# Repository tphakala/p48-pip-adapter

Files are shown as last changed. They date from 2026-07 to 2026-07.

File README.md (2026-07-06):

# P48 → 8 V PIP adapter (fits inside an XLR connector)

An ultra-compact **phantom-power (24-48 V) to 8 V plug-in-power (PIP)** adapter
board for high-sensitivity electret condenser capsules such as the PUI Audio
**AOM-5024**. The whole circuit lives on a **11.1 × 35.3 × 0.8 mm** four-layer
PCB thin enough to slip *between* the pins of a Neutrik **NC3MXX** male XLR and
solder to them directly, so a two-wire electret becomes a self-contained,
buffered, impedance-balanced phantom mic with nothing hanging off the back. It
runs on standard phantom power from any mixer, audio interface (such as a
Focusrite Scarlett), or field recorder.

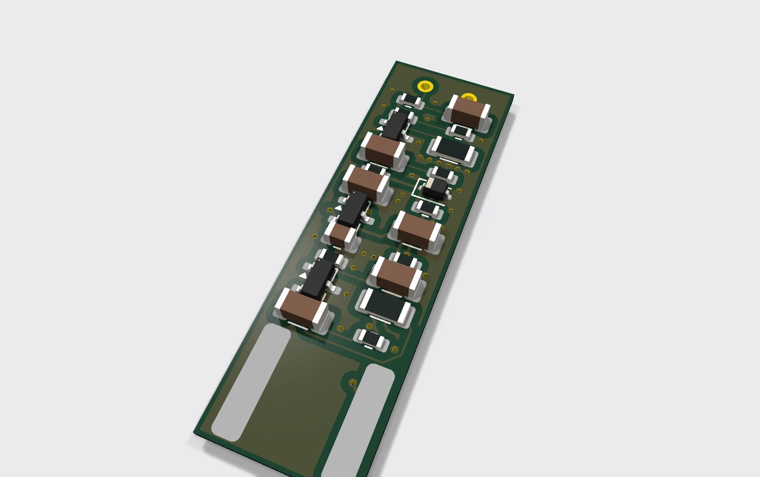
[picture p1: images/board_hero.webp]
Populated adapter board


This is the active-electronics counterpart to the 3D-printed
[`aom5024-xlr`](https://github.com/tphakala/aom5024-xlr) pencil-mic housing.
That project runs the capsule on a bare resistor + capacitor (fine for short
cable runs); this board is the buffered, impedance-balanced front end it points
to for long cables and true common-mode rejection, squeezed onto a board that
still fits inside the connector.

> **Order the bare board as 0.8 mm thick.** The thin edge has to fit into the
> gap between the three Neutrik pins; a standard 1.6 mm board is far too thick.
> This is a deliberate, load-bearing spec, not a default you can ignore.

## How it works

The circuit is three parts, one per section below: a capacitance-multiplier
supply that cleans up the phantom rail, a matched pair of Class-A buffers that
drive the cable, and a current split that keeps the DC draw equal on both
phantom pins.

### 1. Power supply: capacitance multiplier

Rather than running the capsule off a noisy Zener directly, the supply is a
**capacitance multiplier**:

- Phantom power is tapped equally from XLR pins 2 and 3.
- An 8.2 V Zener (D1) sets a raw voltage reference.
- A large RC low-pass (100 kΩ + 22 µF) puts the corner well below 1 Hz,
  scrubbing the Zener's avalanche noise off the reference.
- An NPN emitter follower (Q1) buffers that silent reference to the ~7.5 V
  PIP rail that biases the capsule.

### 2. Audio stage: impedance-balanced Class-A buffer

A two-wire electret can't produce a true differential signal on its own, so the
board fakes a balanced line the preamp can't tell from the real thing:

- **Pin 2 (hot)** is driven by a PNP emitter follower (Q2), a Class-A buffer
  that converts the capsule's high output impedance to a low ~78 Ω that
  drives long cable without treble roll-off.
- **Pin 3 (cold)** uses an identical PNP (Q3) with its base AC-grounded: no
  audio, but it matches Q2's ~78 Ω output impedance exactly.
- To the preamp this looks like a balanced source, so common-mode hum and RF
  cancel.

### 3. DC current balancing

The circuit pulls roughly **3 mA per pin**, a balanced DC draw that suits any
balanced input, whether electronically balanced (most audio interfaces and
modern preamps) or transformer-coupled: pin 2 feeds the hot buffer (Q2); pin 3
feeds the cold buffer (Q3) plus the regulator.

## Simulated performance

The circuit is verified headlessly in **ngspice**. The deck is generated from
[`netlist.py`](netlist.py), the same single source of truth as the board and
schematic, so the simulation can't drift from the hardware. `sim/run.ps1`
range-checks 17 design assertions; `sim/plot_response.py` sweeps the wide-band
response below (10 Hz – 384 kHz).

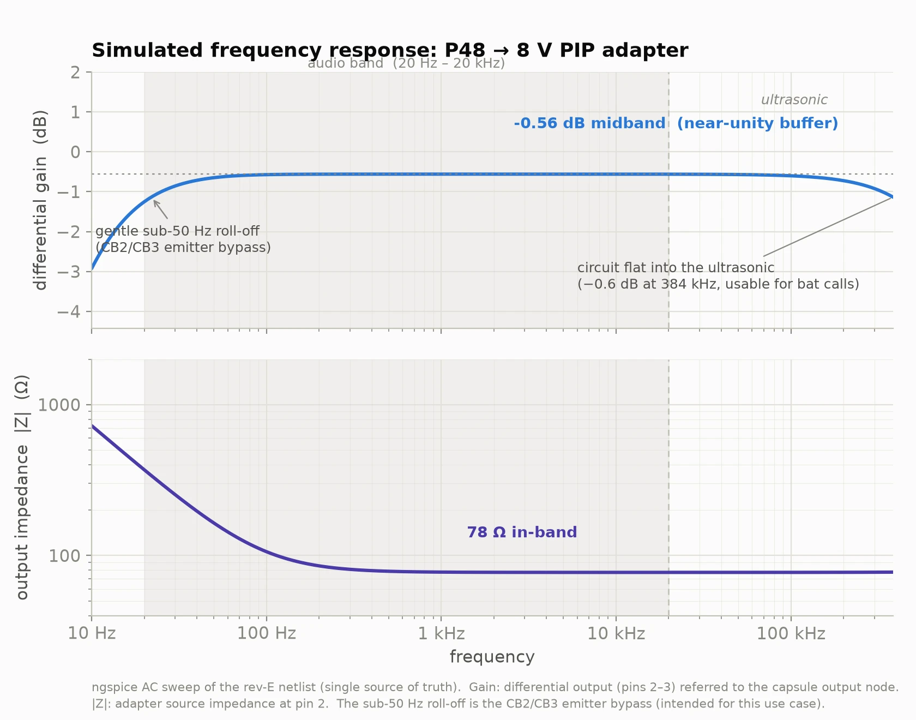
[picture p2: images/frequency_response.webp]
Simulated frequency response


- **Flat through the audio band** at −0.56 dB (a near-unity buffer), driving a
  modelled ~30 m cable into a 2 kΩ preamp.
- **Flat well into the ultrasonic**: only ~0.6 dB down at **384 kHz** (the
  192 kHz Nyquist of a 384 kHz sample rate). The trace is referred to the
  capsule output node, so it shows the *adapter electronics in isolation*: with
  a wide-band capsule the circuit is not the bottleneck for ultrasonic work such
  as **bat-call recording**. (The stock AOM-5024 electret rolls off far earlier;
  swap it for an ultrasonic-capable capsule for that use.)
- **~78 Ω source impedance**, flat from the audio band into the ultrasonic, low
  enough to drive long cable without HF loss and to look benign to any balanced
  input.
- The **gentle sub-50 Hz roll-off** is the CB2/CB3 emitter bypass, and it is
  deliberate: some LF attenuation is desirable here and it keeps those bypass
  caps small.

See [`sim/README.md`](sim/README.md) for the harness and the full assertion list.

## The board

Four copper layers, everything on the **top** side for single-sided assembly.
The two inner layers are **solid ground planes**, a real on-board Faraday cage
for the µV front end, via-stitched to the outer ground pours and to the XLR
pin-1 ground, backing up the grounded zinc shell:

| Layer | Net / role |
| :-- | :-- |
| **F.Cu** | signal routing + all component placement, GND flood-fill |
| **In1.Cu** | solid ground plane (shield / image plane under the signal) |
| **In2.Cu** | solid ground plane (second reference for the back-side routing) |
| **B.Cu** | GND pour + the few signal escapes + the XLR pin-3 pad |

Signal routing is confined to the outer layers so the inner planes stay
unbroken; the supply nets (P2/P3/VPIP/VREF) use a wider 0.25 mm **Power**
netclass, while GND is distributed by the planes rather than as tracks.

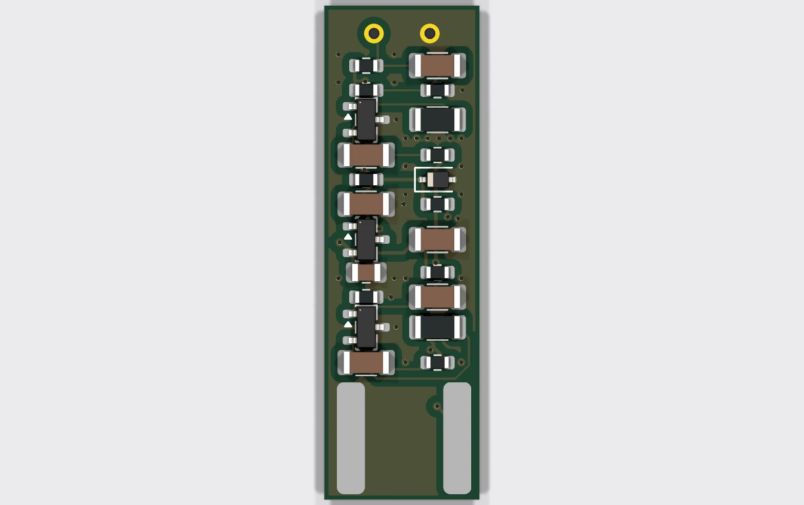
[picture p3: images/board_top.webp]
Top side, the two-column component layout


### XLR sandwich mount

The thin board edge slides **between** the three NC3MXX pins (7.62 mm cup
spacing) and the pins solder to the board faces, pins 1 and 2 on the front and
pin 3 on the back:

| Pin | Net | Face | x (mm) |
| :-- | :-- | :-- | :-- |
| 1 | GND | front | 1.90 |
| 2 | hot | front | 9.52 |
| 3 | cold | back | 5.71 |

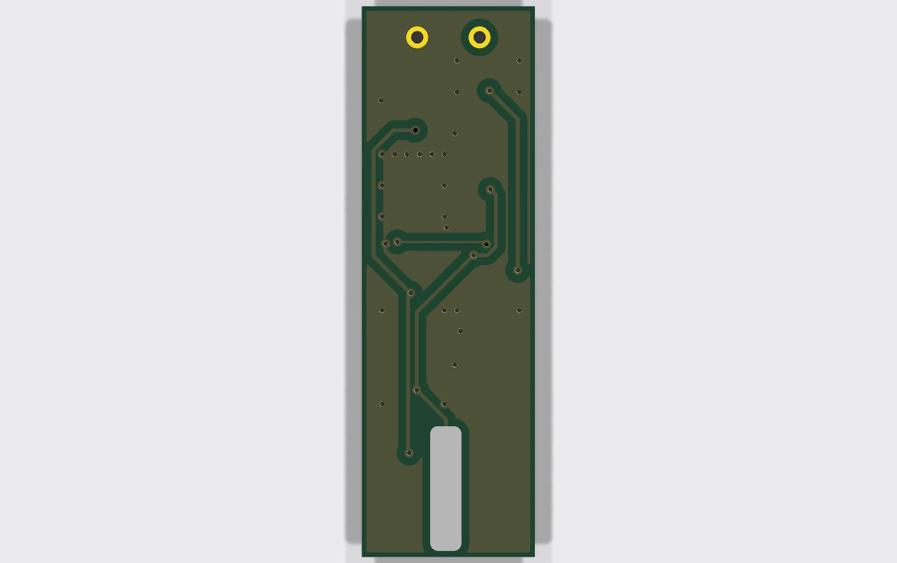
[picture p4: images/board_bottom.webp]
Reverse side: the centred pin-3 pad


The three XLR pads are **8 mm long**: the internal Neutrik pin runs ~5 mm along
the board and the pad extends 3 mm past the pin tip so there's copper to hand-
solder to. The pin tip keeps ≥ 5 mm clearance to the nearest component; the
35.3 mm board length is *derived* from that constraint in `netlist.py`.

The board's thin edge slots straight **between** the three XLR pins (pins 1 & 2
against the front component face, pin 3 against the back), with the pad end
seated against the connector body and the mating pins left free for the preamp.

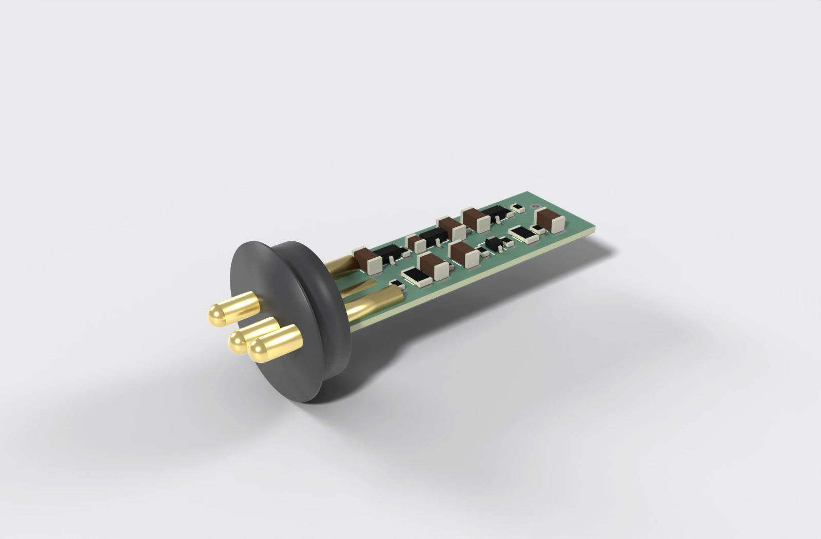
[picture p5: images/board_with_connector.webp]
The board slotted between the three pins of an XLR connector


<sub>The bare pin insert is modelled at this board's actual XLR-pad positions
(from `netlist.py`) to show the sandwich mount; the Neutrik NC3MXX STEP is one
fused solid whose pins can't be isolated, so the pins are drawn to match.</sub>

## Schematic

The full circuit, drawn from [`netlist.py`](netlist.py), the single source of
truth. On the left, the capacitance-multiplier reference/regulator (D1 zener,
R9/C4 sub-1 Hz filter, Q1 emitter follower) produces the clean **VPIP** rail; R10
biases the capsule; and the two impedance-matched PNP emitter followers (Q2 hot,
Q3 cold) draw the balanced ~3 mA per phantom pin, each with its CBx/RBx emitter-
bypass network for the low-Z output. This figure is drawn directly from the same
netlist that synthesizes the board, so the two cannot disagree.

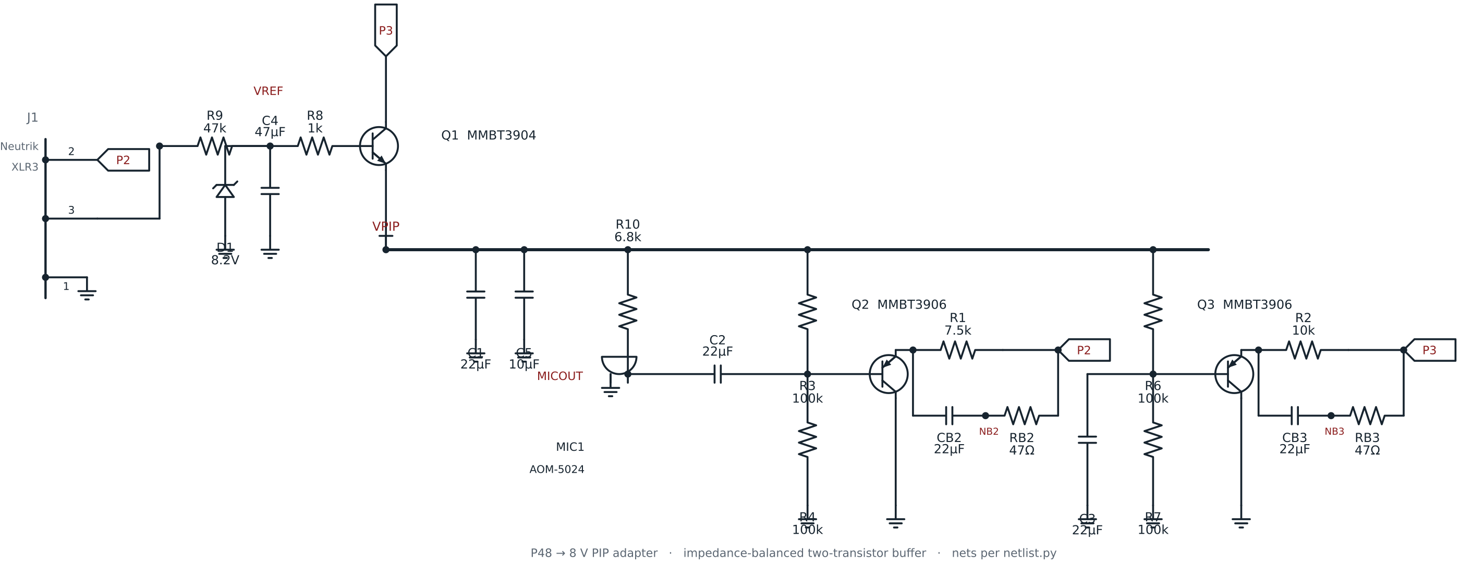
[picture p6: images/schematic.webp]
Schematic


## Bill of materials

All parts are SMD to fit the 11.1 mm width. Component values are nominal
(derived from the architecture and standard P48→PIP practice) and may benefit
from bench tuning before a production run.

| Ref | Value | Package | Function |
| :-- | :-- | :-- | :-- |
| Q1 | MMBT3904 | SOT-23 | NPN, regulator emitter follower |
| Q2, Q3 | MMBT3906 | SOT-23 | PNP, hot / cold audio buffers |
| D1 | 8.2 V Zener | SOD-323 | voltage reference |
| C1, C2, C3 | 22 µF 50 V | 1206 | filtering / DC blocking |
| C4 | 47 µF 50 V | 1206 | VREF filter (sub-1 Hz corner) |
| C5 | 10 µF 16 V | 0805 | PIP rail bypass |
| CB2, CB3 | 22 µF 50 V X7R | 1206 | emitter bypass → low-Z output |
| R1 | 7.5 kΩ | 1206 | hot buffer emitter feed (thermal, 1206) |
| R2 | 10 kΩ | 1206 | cold buffer emitter feed (thermal, 1206) |
| R3, R4, R6, R7 | 100 kΩ | 0603 | bias dividers |
| R8 | 1 kΩ | 0603 | regulator base stopper |
| R9 | 47 kΩ | 0603 | VREF feed |
| R10 | 6.8 kΩ | 0603 | mic bias |
| RB2, RB3 | 47 Ω | 0603 | emitter-bypass series stopper (cable stability) |

R1/R2 are **1206** (not 0603): each dissipates continuously inside the sealed
XLR shell, and 1206's 250 mW rating keeps a comfortable margin at 80 °C ambient.
CB2/CB3 sit across ~23 V DC, so they **must be 50 V rated** (X7R). There is
intentionally **no R5**. The full derived netlist (the single source of truth)
lives in [`netlist.py`](netlist.py) and is documented in [SPEC.md](SPEC.md); the
board is synthesized from it (schematic-free) and the schematic figure above is
drawn from the same netlist, so they cannot disagree.

## Manufacturing status

- **4-layer, 11.1 × 35.3 × 0.8 mm**, all parts top-side (single-sided assembly).
- **DRC: 0 errors, 0 unconnected pads, 0 footprint errors** (`kicad-cli pcb drc`).
- Track 0.15 mm (0.25 mm on the Power netclass), clearance 0.125 mm, vias
  0.6 / 0.3 mm, copper-to-edge ≥ 0.25 mm, solid In1/In2 ground planes with GND
  via stitching, all within JLCPCB / PCBWay standard 4-layer capability.
- Fab package: Gerber X2 + Excellon drill (PTH/NPTH separated) in
  [`Gerbers_PCBWay/`](Gerbers_PCBWay), zipped as `P48_Adapter_PCBWay.zip`.

**Known trade-off.** At 11.1 mm wide with six 1206 caps and two 1206 resistors,
the KiCad *courtyards* (assembly keep-out margins, ~4.7 mm for a 1206) unavoidably
overlap. There are no copper shorts (pad-to-pad clearance is fully enforced), so
the `courtyards_overlap` rule is downgraded to a warning. To remove it entirely,
move the 1206 parts to smaller packages or widen the board. Silkscreen reference
designators are hidden (illegible at this density); use the BOM and placement
data for assembly.

## Mechanical fit test

Before committing to a fab run, print `fit_test/p48_fittest.stl` and check the
board actually fits inside your connector. It's a single manifold solid: the
exact 0.8 mm outline, capsule through-holes, every component embossed at true
body size and height, raised solder pads, and the three long flat XLR solder
pads running along the board from the connector edge. Print flat, components up.

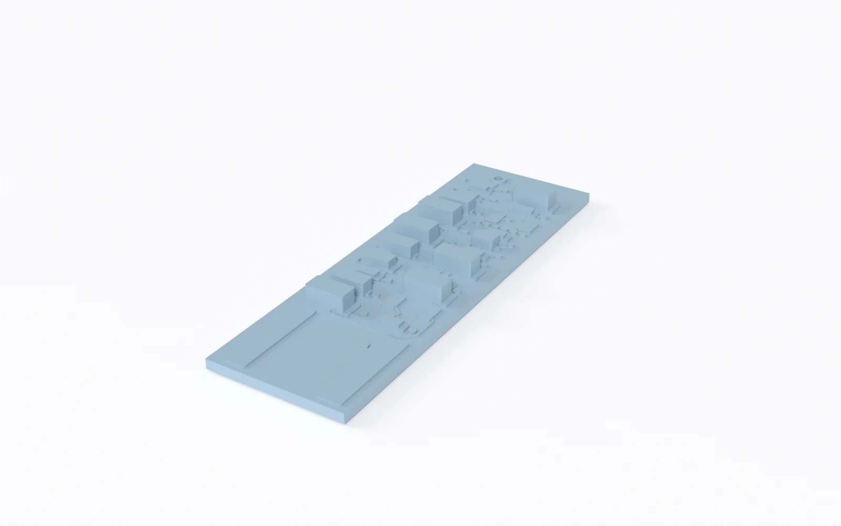
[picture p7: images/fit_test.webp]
3D-printable fit-test coupon


### Soldering to the connector

The board mounts as a sandwich between the Neutrik pins: pins 1 and 2 solder to
the front face, pin 3 to the back. Verified geometry (official KiCad Neutrik
NC3FAAV footprint, corroborated by the printed fit test): pins 1 and 2 are
coplanar and 7.62 mm apart; pin 3 is centred 4.45 mm off their plane. With the
~3 mm solder cups and the 0.8 mm board, pin 3 clears by only ~1.4 mm (about
0.6 mm of total slack), so when the board is seated flush against pins 1 and 2,
the pin-3 cup sits roughly 0.5 to 0.7 mm off its back-face pad and needs a
deliberately fat fillet to bridge the gap.

Solder in this order:

1. **Pre-tin** the pin-3 back-face pad **and** the pin-3 solder cup separately.
2. Seat the board flush against pins 1 and 2 and **solder those two joints
   first**: they set the board position.
3. **Bridge pin 3 last**, reflowing both pre-tinned surfaces into one fat fillet
   across the ~0.6 mm gap.

Soldering pins 1 and 2 before pin 3 keeps the board from being stressed while
it is wedged between the cups.

## Automated build pipeline

The whole board is generated headlessly from `netlist.py`, with no manual KiCad
editing. Steps that touch `pcbnew` run under KiCad's bundled Python; the rest
run under any Python 3.

```bash
KPY="$LOCALAPPDATA/Programs/KiCad/10.0/bin/python.exe"

"$KPY" route.py            # build a pristine board + route it (build_pcb + Freerouting)
python export_gerbers.py   # Gerbers + drill -> Gerbers_PCBWay/ + zip
python gen_fittest.py      # 3D-printable fit-test STL
python scripts/render_previews.py   # regenerate the images/ previews
```

- **`build_pcb.py`**: schematic-free board synthesis. Loads standard + custom
  (XLR / capsule) footprints, assigns every pad to its net, sets the 4-layer
  stackup, the Power netclass and design rules, draws the outline, places all
  parts with a collision-checked parametric auto-placer (two columns, all
  top-side), lays the solid In1/In2 GND planes and pours, and drops the GND
  stitch + pad-fanout via grid.
- **`route.py`**: regenerates a pristine board, exports a Specctra DSN,
  **relabels the inner layers as plane layers** so signal routing stays on the
  outer copper and the GND planes stay unbroken, runs **Freerouting fully
  headless** (`-Djava.awt.headless=true` + `gui.enabled=false`, no window ever
  opens), imports the routes with a built-in SES parser, then floods F.Cu/B.Cu
  with GND and refills. Result: 100 % routed, 0 unconnected.
- **`export_gerbers.py`**: Gerber X2 + Excellon via `kicad-cli`, zipped for fab.
- **`gen_fittest.py`**: extracts the routed geometry into the fit-test STL.
- **`scripts/render_previews.py`**: the preview images above, from the board
  (kicad-cli raytracer) and the fit-test STL (Blender).
- **`scripts/render_connector.py`**: the sandwich-mount render. Exports the
  board to GLB and renders it in Blender between three modelled gold pins placed
  at the board's real XLR-pad positions (no third-party connector model needed).
- **`scripts/gen_schematic.py`**: the wired schematic figure, drawn from
  `netlist.py` with schemdraw (SVG → WebP via Inkscape). This is the schematic
  of record: the board is synthesized directly from the netlist, so there is no
  separate hand-drawn KiCad schematic to fall out of sync.

### Toolchain

Built with **KiCad 10**, `kicad-cli`, **Freerouting**, **Blender** (previews)
and **OpenSCAD** (fit-test model). Tool paths in the scripts are set for the
author's Windows install (`route.py`, `export_gerbers.py`); adjust them, or set
the `KICAD_CLI` / `BLENDER` environment variables the render script reads, for
your own machine.

## Design notes

Dimensional provenance, the full derived netlist, and the reasoning behind the
placement and design rules live in [SPEC.md](SPEC.md).

## License

[CC BY-NC 4.0](LICENSE) (Creative Commons Attribution-NonCommercial). You are
free to build, modify and share this design with attribution.
**Commercial use is not permitted.** Do not sell this board, assembled units,
or derivatives of the design.

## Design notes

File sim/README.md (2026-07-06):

# P48 → 8 V PIP adapter: ngspice simulation harness

Headless SPICE verification of the adapter circuit. The deck is **generated from
`../netlist.py`**, the same single source of truth the schematic figure and the
PCB derive from, so the simulation cannot drift away from the board.

The tables below are the **rev-E** results (the CB2/CB3+RB2/RB3 emitter-bypass
low-Z output stage); `run.ps1` range-checks 17 assertions and all pass.

```
sim/
├── gen_deck.py            # imports ../netlist.py, writes p48.cir (stdlib only)
├── run.ps1               # regenerate → run ngspice → parse → assert (exit code)
├── plot_response.py      # wide-band AC sweep → ../images/frequency_response.webp
├── models/
│   ├── zener_bzx84c8v2.lib   # D1, datasheet-derived (Nexperia BZX84-C8V2)
│   ├── bjt_mmbt390x.lib      # Q1 (NPN 3904), Q2/Q3 (PNP 3906)
│   └── jfet_j201.lib         # capsule stand-in (NOT a board part)
├── p48.cir               # GENERATED, do not edit (git-ignored)
└── out.log              # ngspice listing (git-ignored)
```

## Install ngspice (Windows)

KiCad 10 ships only `ngspice.dll` (its Eeschema engine); there is **no CLI**
under `%LOCALAPPDATA%\Programs\KiCad\10.0\bin`, so install the standalone CLI:

1. Download the official Windows build (64-bit) from the ngspice project on
   SourceForge, current release **v46**, file `ngspice-46_64.7z`
   (`ng-spice-rework/46/`). Verify the md5 shown on the download page.
2. Extract with 7-Zip; it unpacks to `Spice64\`. Put `Spice64\bin` on your PATH
   (that dir holds `ngspice_con.exe`, the console/batch binary this harness uses).
3. Check: `ngspice_con.exe --version` → `ngspice-46 ...`.

Alternatives: `choco install ngspice` (needs an elevated shell; currently
packages v46). `winget` does not carry it as of this writing.

Optional cross-check tool: LTspice (freeware) can open the same cards for
interactive poking; not required for the deliverable.

## Run

```powershell
pwsh -File sim\run.ps1        # or: powershell -File sim\run.ps1
```

`run.ps1` regenerates `p48.cir`, finds ngspice (PATH → common install dirs),
runs `ngspice_con -b p48.cir`, parses every `name = value` it prints, and
range-checks the pass criteria. **Exit 0 = all pass, exit 1 = a failure**
(ngspice does not fail its own process on a `.meas` miss, so the script does it).

Run the deck by hand:

```powershell
ngspice_con.exe -b sim\p48.cir      # (run from the sim/ dir so .include resolves)
```

## Frequency-response plot

```
python sim/plot_response.py          # needs: pip install matplotlib pillow
```

`plot_response.py` reuses `gen_deck`'s component cards + harness, runs two AC
sweeps (10 Hz – 384 kHz: the audio band plus the ultrasonic range up to the
192 kHz Nyquist of a 384 kHz sample rate) and writes
`../images/frequency_response.webp`: differential gain and output impedance vs
frequency. The gain trace is referred to the capsule output node, so it shows
the adapter electronics in isolation (the circuit is flat well into the
ultrasonic; the capsule sets the real HF limit).

## What each analysis checks

Expected values are the hand-derived numbers from the 2026-07-06 design review
(issues #2/#3/#5/#6/#9); ±15 % is allowed where the zener dominates.

| # | Analysis | Confirms | rev-E sim result |
|---|---|---|---|
| 1 | `.op` operating point | #3, #5 | V(P2)=27.6 V, V(P3)=27.3 V, I(pin2)=3.00 mA, I(pin3)=3.03 mA, VPIP=7.37 V, I(D1)=408 µA, pin imbalance 37 µA |
| 2 | `.ac` output impedance at pin 2 | #2, #11 | **~78 Ω, flat** 1 k–20 kHz (0.004 flatness), the emitter bypass, down from ~10 kΩ |
| 3 | `.ac` gain, capsule→differential | #2, #6 | **−0.56 dB @ 1 kHz** (near-unity buffer); passband flat 100 Hz–20 kHz to 0.009 dB; LF droop 0.69 dB @ 20 Hz; polarity **inverting** |
| 4 | `.tran` startup 0–15 s (cold) | #9 | max Vce(Q1)=23.1 V (< 35 V); VPIP at 90 % in **~0.8 s**, settled 7.38 V |
| 5 | `.tran` polarity blip | #6 | down-gate-step → up-output ⇒ inverting (agrees with #3) |
| 6 | `.noise` at the output | n/a | informational only (see caveat) |

### Findings the sim surfaced (fed into rev-E)

- **Output impedance is now ~78 Ω**, flat across the audio band, set by the rev-E
  CB2/CB3+RB2/RB3 emitter bypass that takes the output at Q2/Q3's low-Z emitters,
  down from the baseline ~10 kΩ, and low enough to drive long cable without HF loss.
- **The bass roll-off is now a gentle, deliberate 0.69 dB at 20 Hz.** The baseline's
  ~4 dB VPIP-bypass droop is gone; the remaining sub-50 Hz taper is set by the
  emitter-bypass caps against their DC-bias derating, which is desirable here and
  keeps CB2/CB3 small (no oversizing / polymer needed).
- **Startup** reaches 90 % of VPIP in ~0.8 s and is settled by ~2 s (well under the
  ~5–10 s #9 estimate): the zener clamps VREF long before R9·C4 fully charges.
- **Polarity is inverting** (positive gate excursion → negative-going differential
  output), matching the #6 topology prediction. The *capsule-construction* half of
  #6 still needs the bench.

## Model caveats (read before trusting the numbers)

- **Zener (`BZX84C8V2`) is datasheet-DERIVED, not a vendor `.lib`.** Nexperia does
  not publish a downloadable SPICE model and the vendor download endpoints block
  scripted access, so the model is fitted to the Rev.7 datasheet reverse curve
  (Vz=8.2 V and rdif=15 Ω at 5 mA, rdif=80 Ω at 1 mA, the soft knee). At the
  rev-E ~410 µA operating point (R9 47k) it predicts VREF≈8.0 V ⇒ VPIP≈7.37 V.
  That is ~0.2 V above the review's 6.5–7.2 V estimate: the datasheet's max rdif
  bounds how soft the knee can be, so the real part sags *less* than hand-estimated.
  If you obtain the official vendor model, drop it in `models/` (keep the name
  `BZX84C8V2`) and re-run. See the file header for the fit rationale + source URL.
- **Zener noise is not modelled.** SPICE has no avalanche-noise magnitude, so the
  absolute self-noise from analysis 6 is meaningless; it only shows the R9/C4
  filter shape. No assertion is placed on it.
- **BJTs** use the canonical 2N3904/2N3906 die models (accepted stand-ins for the
  SOT-23 MMBT390x per issue #10).
- **Capsule** is a J201 JFET proxy for the electret's internal common-source
  buffer (gate at Vgs≈0, ~Idss, as a real electret self-biases). It sets absolute
  gain and the capsule DC operating point; the real AOM-5024 transconductance and
  output polarity are bench items.

## Using the harness for further tweaks

rev-E already folds in the review's key changes: R9 100k → 47k (#3, ~doubles the
zener bias) and R1 10k → 7.5k (#5, rebalances the pin-2 current), plus the
CB2/CB3+RB2/RB3 emitter bypass, which made the earlier "C1/C5 → 220 µF for flat
bass" idea unnecessary (the sub-50 Hz taper is now deliberate). Use the harness to
A/B any further change (edit `../netlist.py`, re-run):

- **C2 ↔ C3 swap (#6):** the ready polarity fix *if* the bench confirms the capsule
  is inverted; it moves the driven leg to pin 3. Documented in `netlist.py`; do not
  apply blind.
- Bias re-tuning, or dropping in an official vendor zener model, then re-running
  the 17 assertions.

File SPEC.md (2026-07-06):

# P48 → 8 V PIP adapter: design notes

Engineering and provenance notes for the miniature phantom-power to plug-in-
power adapter generated from [`netlist.py`](netlist.py). See
[README.md](README.md) for the user-facing overview (architecture, BOM,
manufacturing, fit test). This file records **where the numbers came from** and
why the layout is shaped the way it is.

> **Status (rev-E):** `netlist.py`, the board, the fab package and the schematic
> figure are all the rev-E low-noise design (emitter-bypass buffer CB2/CB3+RB2/RB3,
> R1→7.5k, R1/R2 in 1206, R8→1k, R9→47k, C4→47µF, XLR_CLEARANCE 3.5 mm), verified
> by the `sim/` harness. The inner copper is now two **solid GND planes** with via
> stitching (git.koti #1) and the supply nets carry a real **Power** netclass (#7).

## Netlist provenance

The schematic originally delivered with the design carried **no connectivity**.
The netlist below was reconstructed from the architecture description (buffered,
impedance-balanced, ~3 mA/pin) and standard P48→PIP practice, and is now the
single source of truth in `netlist.py`. The design is **schematic-free**: the
board (`build_pcb.py`) is synthesized directly from the netlist and the schematic
figure (`scripts/gen_schematic.py` → `images/schematic.webp`) is drawn from the
same netlist, so they can never drift apart.

Component **values are nominal**: they follow from the topology and typical
practice, not from a bench-tuned prototype. Bias values in particular may want
tuning before a production run; the topology is what drives layout and routing.

### Derived netlist (authoritative)

| Net | Connections (ref.pad) | Function |
| :-- | :-- | :-- |
| **GND** | J1.1, MIC1.2, D1.A, C4.2, C5.2, C1.2, R4.2, R7.2, C3.2, Q2.C, Q3.C | XLR pin 1 / 0 V (solid In1/In2 planes) |
| **P2** | J1.2, R1.1, RB2.2 | XLR pin 2 (hot), Q2 draws ~3 mA |
| **P3** | J1.3, R9.1, Q1.C, R2.1, RB3.2 | XLR pin 3 (cold), Q3 + regulator draw ~3 mA |
| **VPIP** | Q1.E, C1.1, C5.1, R10.1, R3.1, R6.1 | ~7.5 V plug-in-power rail |
| **VREF** | R9.2, D1.K, C4.1, R8.1 | filtered 8.2 V Zener reference |
| **Q1B** | R8.2, Q1.B | regulator base (buffered VREF) |
| **MICOUT** | MIC1.1, R10.2, C2.1 | capsule signal node |
| **Q2B** | R3.2, R4.1, C2.2, Q2.B | hot buffer base (bias + AC-coupled signal) |
| **Q2E** | R1.2, Q2.E, CB2.1 | hot buffer emitter (low-Z output node) |
| **Q3B** | R6.2, R7.1, C3.1, Q3.B | cold buffer base (AC-grounded) |
| **Q3E** | R2.2, Q3.E, CB3.1 | cold buffer emitter (low-Z output node) |
| **NB2** | CB2.2, RB2.1 | hot emitter-bypass mid-node |
| **NB3** | CB3.2, RB3.1 | cold emitter-bypass mid-node |

Pad roles: SOT-23 pad 1 = B, 2 = E, 3 = C (matches the KiCad MMBT390x symbols);
D_Zener pad 1 = K (cathode), 2 = A (anode); R/C pads 1, 2. The **emitter-bypass
network** (rev-E) AC-couples each buffer's low-impedance emitter to its phantom
pin: `Q2E → CB2(22µF) → NB2 → RB2(47Ω) → P2` (and the cold-side mirror), dropping
the output impedance from ~10 kΩ to ~78 Ω while R1/R2 still set the DC current.

### Circuit derivation

**Reference / PIP supply** (fed from XLR pin 3, the "cold/quiet" pin):
`P3 → R9(47k) → VREF`; D1 (8.2 V Zener) clamps VREF to GND; C4 (47 µF) filters it
(R9·C4 ≈ 0.07 Hz, sub-1 Hz). Q1 (NPN) is an emitter follower: base = VREF via
the R8 (1 k) stopper, collector = P3, emitter = VPIP (~7.5 V), bypassed by
C1 (22 µF) + C5 (10 µF).

**Capsule bias:** `VPIP → R10(6.8k) → MICOUT`; the capsule sits between MICOUT and
GND.

**Hot buffer** (draws ~3 mA from pin 2, carries the audio): Q2 (PNP) base = Q2B,
set by the R3/R4 divider off VPIP with the capsule signal AC-coupled in through
C2; emitter = Q2E fed from P2 through R1 (7.5 k). The rev-E emitter-bypass network
`Q2E → CB2(22µF) → NB2 → RB2(47Ω) → P2` AC-couples the low-impedance emitter to
the pin, so the output impedance is ~78 Ω (not R1's 7.5 kΩ) while R1 still sets
the DC current; collector = GND. Signal current modulates the pin-2 current →
audio on the hot leg.

**Cold buffer** (draws a matched ~3 mA from pin 3, no signal): Q3 (PNP)
identical to Q2 but with its base Q3B AC-grounded by C3; divider R6/R7; emitter
= Q3E fed from P3 through R2 (10 k) with the matching `CB3/RB3` bypass to P3;
collector = GND. It matches the pin-2 output impedance so the source looks
balanced to the preamp.

## Board geometry

```
BOARD_W = 11.1 mm     fixed by the NC3MXX chuck bore
BOARD_T = 0.8 mm      the edge must slip between the XLR pins
BOARD_L = 35.3 mm     DERIVED (see below)
```

**Nothing is placed by absolute-coordinate patching.** Positions come from a
two-column auto-placer working from the real footprint pad sizes, so the layout
is reproducible from `netlist.py` alone.

- **Why two columns:** KiCad's 1206 courtyard is 4.69 mm wide, so only two wide
  parts fit across an 11.1 mm board. The 22 SMD parts are ordered by signal flow
  and snaked into the two columns so connected parts stay adjacent: mic/Q2 input
  and its CB2/RB2 emitter-bypass, then reference/regulator, then the Q3 cold
  buffer and its CB3/RB3 bypass. Keeping each output stage's bypass beside its
  transistor is both a routing win and a low-noise win (tight bypass loops).
- **Row pitch** is set by the *actual* pad-copper extents plus a copper-to-copper
  gap, so no pad ever shorts to its neighbour even where courtyards overlap.
- **Board length is derived, not chosen.** The XLR solder pad is 8 mm long
  (5 mm internal pin + 3 mm past the tip for solder access). The last component
  row, plus a required 5 mm pin-tip-to-component clearance, plus the pad and a
  small edge gap, fix `BOARD_L`. Change the component set and the board length
  follows automatically.

## Stackup and design rules

- 4 layers: F.Cu (signal + parts + GND pour), **In1.Cu + In2.Cu (both solid GND
  planes)**, B.Cu (GND pour + signal escapes + the XLR pin-3 pad).
- The inner planes are a real shield for the µV front end. Signal routing is
  confined to the outer layers (the DSN relabels In1/In2 as plane layers) so the
  planes stay unbroken; a grid of GND through vias stitches all four layers and
  a fanout via ties every GND pad to the planes.
- Track 0.15 mm, clearance 0.125 mm, vias 0.6 mm / 0.3 mm drill.
- Copper-to-edge ≥ 0.25 mm (an edge keepout enforces a fab-safe margin).
- Supply nets **P2, P3, VPIP, VREF** carry a wider 0.25 mm "Power" netclass
  (`build_pcb.patch_project_netclass`); GND is distributed by the planes, not a
  track, so it stays on the default class.

All within JLCPCB / PCBWay standard 4-layer capability.

## Custom footprints

Two footprints are built inline by `build_pcb.py` rather than pulled from a
library:

- **`XLR_SolderCup`**: three THT face pads at the NC3MXX cup spacing. Pins 1
  and 2 sit on the front face (x = 1.90, 9.52 mm), pin 3 on the back face
  (x = 5.71 mm, centred). Each pad is 8 mm long. This is the "sandwich" mount:
  the board edge goes between the pins, so `BOARD_T` (0.8 mm) must be less than
  the pin-1/2 to pin-3 gap.
- **`MIC_2pad`**: two through-hole solder points at the top edge for the
  AOM-5024 capsule leads (0.8 mm drill, 1.4 mm pad).

## Known trade-offs

- **Courtyard overlap.** Six 1206 caps and two 1206 resistors on an 11.1 mm board
  force the assembly courtyards to overlap. There are **no copper shorts**
  (pad-to-pad clearance is enforced), so `courtyards_overlap` is downgraded to a
  warning rather than an error. Move the 1206 parts to smaller packages or widen
  the board to eliminate it.
- **Hidden silkscreen designators.** At this density the reference designators
  are illegible, so they're hidden. Assemble from the BOM and placement data.
- **Freerouting determinism.** Routing is done by Freerouting; re-running
  `route.py` regenerates a pristine board and re-routes from scratch (importing
  onto an already-routed board can leave stale inner-layer traces). The routed
  result committed here is what the fab package and previews are built from.

## Verification status

- **DRC:** 0 errors, 0 unconnected pads, 0 footprint errors (`kicad-cli pcb drc`).
- **No separate ERC:** the design is schematic-free. `netlist.py` is the
  connectivity source of truth, `build_pcb.py` synthesizes the board directly
  from it, and `scripts/gen_schematic.py` draws the schematic figure from the
  same netlist, so board and schematic cannot disagree.
- Fab outputs regenerate cleanly from `export_gerbers.py`.

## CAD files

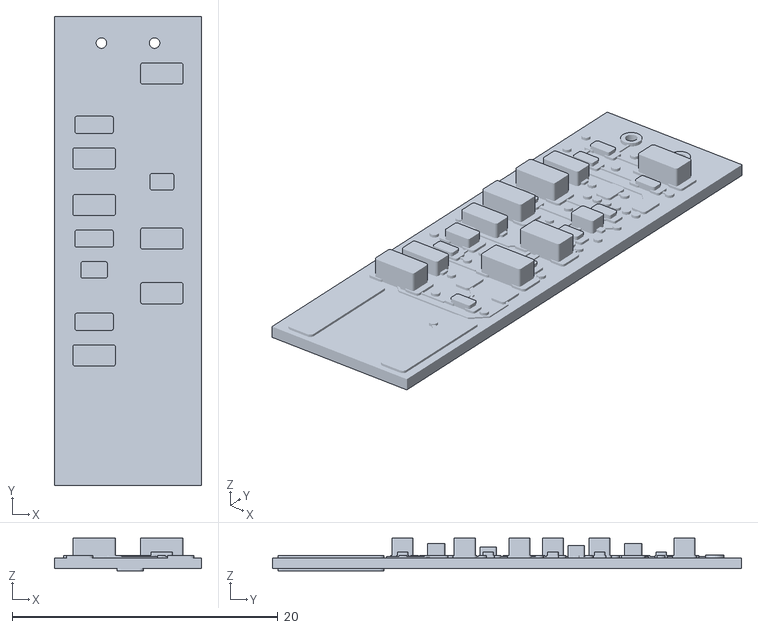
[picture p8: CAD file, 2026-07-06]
fit_test/p48_fittest.stl
11.1 x 35.3 x 2.46

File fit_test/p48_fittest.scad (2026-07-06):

// P48 PIP adapter -- mechanical fit-test model (auto-generated from PCB).
// Board FRONT face (components) is +Z; print flat with components UP.
// The bottom edge (high Y) is the XLR end: pins 1,2 contact the FRONT face
// pads, pin 3 the BACK face pad -- the 0.8 mm board slips between the pins.
// All dims mm.
$fn = 24;

board_w = 11.1;
board_l = 35.325;
board_t = 0.8;        // thin 4-layer PCB thickness (fits between XLR pins)
pad_h   = 0.18;       // solder-point / pad emboss height
trace_h = 0.12;       // top-copper trace emboss height
via_h   = 0.20;       // via emboss height
ring_h  = 0.25;       // through-hole pad ring height
emboss_scale = 1.0;   // scale ALL component heights (e.g. 1.3 for margin)
include_traces = true;

// XLR solder joints are LONG flat pads (not tall posts): they run ALONG the
// board covering the full internal pin length + 3 mm past the pin tip for
// easier soldering.  Pins 1,2 on the FRONT face, pin 3 on the BACK.

// [x, y, w, h, ang] FRONT-face component solder pads
front_pads = [
  [2.175, 14.485000000000003, 0.8, 0.95, -0.0],
  [3.825, 14.485000000000003, 0.8, 0.95, -0.0],
  [2.0625, 13.280000000000001, 1.475, 0.6, -0.0],
  [2.0625, 11.380000000000003, 1.475, 0.6, -0.0],
  [3.9375, 12.330000000000002, 1.475, 0.6, -0.0],
  [1.525, 24.635000000000005, 1.15, 1.8, -0.0],
  [4.475, 24.635000000000005, 1.15, 1.8, -0.0],
  [7.275, 29.270000000000003, 0.8, 0.95, -0.0],
  [8.925, 29.270000000000003, 0.8, 0.95, -0.0],
  [7.275, 21.125000000000004, 0.8, 0.95, -0.0],
  [8.925, 21.125000000000004, 0.8, 0.95, -0.0],
  [6.6375, 27.165000000000003, 1.125, 1.75, -0.0],
  [9.5625, 27.165000000000003, 1.125, 1.75, -0.0],
  [2.0625, 28.115000000000002, 1.475, 0.6, -0.0],
  [2.0625, 26.215000000000003, 1.475, 0.6, -0.0],
  [3.9375, 27.165000000000003, 1.475, 0.6, -0.0],
  [7.05, 22.880000000000003, 0.6, 0.45, -0.0],
  [9.15, 22.880000000000003, 0.6, 0.45, -0.0],
  [6.625, 31.025000000000002, 1.15, 1.8, -0.0],
  [9.575, 31.025000000000002, 1.15, 1.8, -0.0],
  [6.625, 18.595000000000002, 1.15, 1.8, -0.0],
  [9.575, 18.595000000000002, 1.15, 1.8, -0.0],
  [2.0625, 19.545, 1.475, 0.6, -0.0],
  [2.0625, 17.645000000000003, 1.475, 0.6, -0.0],
  [3.9375, 18.595000000000002, 1.475, 0.6, -0.0],
  [2.05, 16.240000000000002, 1.0, 1.45, -0.0],
  [3.95, 16.240000000000002, 1.0, 1.45, -0.0],
  [7.275, 24.635000000000005, 0.8, 0.95, -0.0],
  [8.925, 24.635000000000005, 0.8, 0.95, -0.0],
  [1.525, 21.125000000000004, 1.15, 1.8, -0.0],
  [4.475, 21.125000000000004, 1.15, 1.8, -0.0],
  [2.175, 29.270000000000003, 0.8, 0.95, -0.0],
  [3.825, 29.270000000000003, 0.8, 0.95, -0.0],
  [2.175, 22.880000000000003, 0.8, 0.95, -0.0],
  [3.825, 22.880000000000003, 0.8, 0.95, -0.0],
  [1.525, 9.800000000000004, 1.15, 1.8, -0.0],
  [4.475, 9.800000000000004, 1.15, 1.8, -0.0],
  [6.6375, 12.330000000000002, 1.125, 1.75, -0.0],
  [9.5625, 12.330000000000002, 1.125, 1.75, -0.0],
  [7.275, 16.240000000000002, 0.8, 0.95, -0.0],
  [8.925, 16.240000000000002, 0.8, 0.95, -0.0],
  [7.275, 9.800000000000004, 0.8, 0.95, -0.0],
  [8.925, 9.800000000000004, 0.8, 0.95, -0.0],
  [2.175, 31.025000000000002, 0.8, 0.95, -0.0],
  [3.825, 31.025000000000002, 0.8, 0.95, -0.0],
  [6.625, 14.485000000000003, 1.15, 1.8, -0.0],
  [9.575, 14.485000000000003, 1.15, 1.8, -0.0]
];
// [x, y, w, h, ang] BACK-face component solder pads
back_pads = [

];
// [x, y, pad_w, pad_len, front?] XLR solder pads (1 = front face, 0 = back face)
xlr_joints = [
  [1.9, 4.400000000000002, 2.0, 8.0, 1],
  [9.52, 4.400000000000002, 2.0, 8.0, 1],
  [5.71, 4.400000000000002, 2.0, 8.0, 0]
];
// [x, y, drill, pad_dia] plated through-holes (capsule leads)
tht_pads = [
  [3.55, 33.325, 0.8, 1.4],
  [7.55, 33.325, 0.8, 1.4]
];
// [x, y, body_len, body_wid, height, ang] component bodies
bodies = [
  [3.0, 14.485000000000003, 1.6, 0.8, 0.45, -0.0],
  [3.0, 12.330000000000002, 2.9, 1.3, 1.1, -0.0],
  [3.0, 24.635000000000005, 3.2, 1.6, 1.5, -0.0],
  [8.1, 29.270000000000003, 1.6, 0.8, 0.45, -0.0],
  [8.1, 21.125000000000004, 1.6, 0.8, 0.45, -0.0],
  [3.0, 27.165000000000003, 2.9, 1.3, 1.1, -0.0],
  [8.1, 22.880000000000003, 1.8, 1.25, 0.95, -0.0],
  [8.1, 31.025000000000002, 3.2, 1.6, 1.5, -0.0],
  [8.1, 18.595000000000002, 3.2, 1.6, 1.5, -0.0],
  [3.0, 18.595000000000002, 2.9, 1.3, 1.1, -0.0],
  [3.0, 16.240000000000002, 2.0, 1.25, 0.85, -0.0],
  [8.1, 24.635000000000005, 1.6, 0.8, 0.45, -0.0],
  [3.0, 21.125000000000004, 3.2, 1.6, 1.5, -0.0],
  [3.0, 29.270000000000003, 1.6, 0.8, 0.45, -0.0],
  [3.0, 22.880000000000003, 1.6, 0.8, 0.45, -0.0],
  [3.0, 9.800000000000004, 3.2, 1.6, 1.5, -0.0],
  [8.1, 16.240000000000002, 1.6, 0.8, 0.45, -0.0],
  [8.1, 9.800000000000004, 1.6, 0.8, 0.45, -0.0],
  [3.0, 31.025000000000002, 1.6, 0.8, 0.45, -0.0],
  [8.1, 14.485000000000003, 3.2, 1.6, 1.5, -0.0]
];
// [x1, y1, x2, y2, w] top-copper traces
tracks = [
  [2.175, 13.805000000000003, 2.175, 14.485000000000003, 0.15],
  [2.0625, 13.280000000000001, 2.175, 13.392500000000002, 0.15],
  [5.945, 13.805000000000003, 2.175, 13.805000000000003, 0.15],
  [7.17, 14.485000000000003, 8.925, 16.240000000000002, 0.15],
  [6.625, 14.485000000000003, 7.17, 14.485000000000003, 0.15],
  [2.175, 13.392500000000002, 2.175, 13.805000000000003, 0.15],
  [6.625, 14.485000000000003, 5.945, 13.805000000000003, 0.15],
  [9.575, 20.095000000000002, 9.575, 18.595000000000002, 0.15],
  [9.15, 23.175000000000004, 9.15, 22.880000000000003, 0.15],
  [3.825, 14.485000000000003, 3.95, 14.610000000000003, 0.15],
  [9.8, 14.710000000000004, 9.575, 14.485000000000003, 0.15],
  [9.875, 29.270000000000003, 8.925, 29.270000000000003, 0.15],
  [4.075, 14.485000000000003, 3.95, 14.610000000000003, 0.15],
  [4.775, 14.485000000000003, 4.075, 14.485000000000003, 0.15],
  [9.8, 15.825000000000003, 9.8, 14.710000000000004, 0.15],
  [9.8, 23.825000000000003, 9.15, 23.175000000000004, 0.15],
  [3.95, 14.610000000000003, 3.95, 16.240000000000002, 0.15],
  [2.0625, 10.337500000000002, 3.7422, 8.657800000000002, 0.15],
  [1.525, 9.800000000000004, 2.0625, 10.337500000000002, 0.15],
  [3.7422, 8.657800000000002, 9.3876, 8.657800000000002, 0.15],
  [10.3527, 9.622900000000001, 10.3527, 11.539800000000003, 0.15],
  [2.0625, 10.337500000000002, 2.0625, 11.380000000000003, 0.15],
  [10.3527, 11.539800000000003, 9.5625, 12.330000000000002, 0.15],
  [9.3876, 8.657800000000002, 10.3527, 9.622900000000001, 0.15],
  [3.7394, 28.2601, 2.0625, 26.583200000000005, 0.15],
  [2.0625, 25.172500000000003, 2.0625, 26.215000000000003, 0.15],
  [1.525, 24.635000000000005, 2.0625, 25.172500000000003, 0.15],
  [2.0625, 26.583200000000005, 2.0625, 26.215000000000003, 0.15],
  [9.5625, 27.165000000000003, 8.4674, 28.2601, 0.15],
  [8.4674, 28.2601, 3.7394, 28.2601, 0.15],
  [4.475, 24.635000000000005, 7.275, 24.635000000000005, 0.15],
  [3.825, 29.270000000000003, 7.275, 29.270000000000003, 0.15],
  [2.0625, 28.115000000000002, 2.67, 28.115000000000002, 0.15],
  [9.575, 31.025000000000002, 9.03, 31.025000000000002, 0.15],
  [9.03, 31.025000000000002, 7.275, 29.270000000000003, 0.15],
  [2.67, 28.115000000000002, 3.825, 29.270000000000003, 0.15],
  [3.825, 22.880000000000003, 7.05, 22.880000000000003, 0.25],
  [3.825, 22.880000000000003, 2.07, 21.125000000000004, 0.25],
  [2.07, 21.125000000000004, 1.525, 21.125000000000004, 0.25],
  [7.05, 22.880000000000003, 7.05, 21.35, 0.25],
  [7.05, 21.35, 7.275, 21.125000000000004, 0.25],
  [2.0625, 19.545, 2.5904, 20.072900000000004, 0.15],
  [8.825, 21.025000000000002, 8.925, 21.125000000000004, 0.15],
  [8.825, 20.209300000000002, 8.825, 21.025000000000002, 0.15],
  [2.5904, 20.072900000000004, 3.1123, 20.072900000000004, 0.15],
  [8.925, 24.635000000000005, 7.9813, 23.691300000000005, 0.25],
  [7.6692, 27.364800000000002, 6.8373, 27.364800000000002, 0.25],
  [8.0685, 6.676900000000003, 9.52, 5.225400000000004, 0.25],
  [6.8373, 27.364800000000002, 6.6375, 27.165000000000003, 0.25],
  [9.52, 5.225400000000004, 9.52, 4.400000000000002, 0.25],
  [7.9813, 23.691300000000005, 7.9813, 16.9278, 0.25],
  [3.825, 33.050000000000004, 3.825, 31.025000000000002, 0.15],
  [6.625, 31.025000000000002, 3.825, 31.025000000000002, 0.15],
  [3.55, 33.325, 3.825, 33.050000000000004, 0.15],
  [2.05, 17.632500000000004, 2.0625, 17.645000000000003, 0.25],
  [2.175, 29.906800000000004, 2.9221, 29.906800000000004, 0.25],
  [1.2983, 18.384200000000003, 2.05, 17.632500000000004, 0.25],
  [2.175, 29.906800000000004, 2.175, 29.270000000000003, 0.25],
  [2.175, 31.025000000000002, 2.175, 29.906800000000004, 0.25],
  [2.0625, 17.645000000000003, 5.675, 17.645000000000003, 0.25],
  [5.675, 17.645000000000003, 6.625, 18.595000000000002, 0.25],
  [1.1057, 18.384200000000003, 1.2983, 18.384200000000003, 0.25],
  [6.625, 18.595000000000002, 7.275, 17.945000000000004, 0.25],
  [7.275, 17.945000000000004, 7.275, 16.240000000000002, 0.25],
  [2.05, 16.240000000000002, 2.05, 17.632500000000004, 0.25],
  [7.7991, 11.168400000000002, 7.7991, 10.925900000000002, 0.25],
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

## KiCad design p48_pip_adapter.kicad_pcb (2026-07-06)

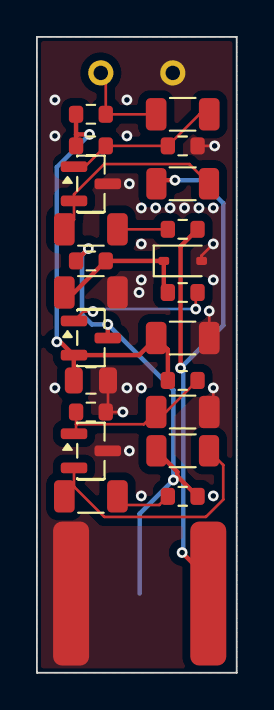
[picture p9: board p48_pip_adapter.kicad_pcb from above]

Board: 4 copper layers, 11.1 x 35.3 mm, 24 parts (0 on the bottom side), 13 nets.

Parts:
C1, C2, C3: 22uF; C_1206_3216Metric
C4: 47uF; C_1206_3216Metric
C5: 10uF; C_0805_2012Metric
CB2, CB3: 22uF; C_1206_3216Metric
D1: 8.2V; D_SOD-323
J1: XLR3
MIC1: AOM5024
Q1: MMBT3904; SOT-23
Q2, Q3: MMBT3906; SOT-23
R1: 7.5k; R_1206_3216Metric
R2: 10k; R_1206_3216Metric
R3, R4, R6, R7: 100k; R_0603_1608Metric
R8: 1k; R_0603_1608Metric
R9: 47k; R_0603_1608Metric
R10: 6.8k; R_0603_1608Metric
RB2, RB3: 47; R_0603_1608Metric

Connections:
GND: C1.2, C3.2, C4.2, C5.2, D1.2, J1.1, MIC1.2, Q2.3, Q3.3, R4.2, R7.2
MICOUT: C2.1, MIC1.1, R10.2
NB2: CB2.2, RB2.1
NB3: CB3.2, RB3.1
P2: J1.2, R1.1, RB2.2
P3: J1.3, Q1.3, R2.1, R9.1, RB3.2
Q1B: Q1.1, R8.2
Q2B: C2.2, Q2.1, R3.2, R4.1
Q2E: CB2.1, Q2.2, R1.2
Q3B: C3.1, Q3.1, R6.2, R7.1
Q3E: CB3.1, Q3.2, R2.2
VPIP: C1.1, C5.1, Q1.2, R3.1, R6.1, R10.1
VREF: C4.1, D1.1, R8.1, R9.2

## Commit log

2026-07-06 Miniature P48 -> 8V PIP adapter: board, fab package, and docs
    A 11.1 x 32.4 x 0.8 mm four-layer adapter that turns a two-wire electret
    (PUI AOM-5024) into a buffered, impedance-balanced phantom microphone, thin
    enough to solder between the pins of a Neutrik NC3MXX XLR.
    - Headless generation pipeline from netlist.py (single source of truth):
    build_pcb.py -> route.py (Freerouting) -> export_gerbers.py, gen_fittest.py.
    - DRC/ERC clean; Gerber X2 + Excellon fab package included.
    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
    [p48_fittest.scad, p48_fittest.stl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]
2026-07-06 Add board-on-connector render and schematic to the README
    - images/board_with_connector.png: the routed board (kicad-cli GLB) plugged
    into a bare 3-pin XLR insert, rendered in Blender. Reproduced by
    scripts/render_connector.py (+ render_connector_blender.py, tmf2stl.py); the
    connector model is third-party and kept local/gitignored (reference/).
    - images/schematic.png: exported from the wired schematic for expert review.
    Schematic paper A4 -> A3 (components no longer overflow the sheet) and a
    title block added.
    [p48_pip_adapter.kicad_sch]
2026-07-06 Recreate schematic as a proper wired diagram; fix connector render
    - images/schematic.png: replace the net-label KiCad export (which read as
    "nothing connected") with a fully wired schematic drawn from netlist.py via
    schemdraw (scripts/gen_schematic.py) -> SVG -> PNG (Inkscape). Topology wired
    by transistor anchor, verified identical to the board netlist.
    - images/board_with_connector.png: flip the XLR connector so the board is on the
    solder-cup end and the mating pins are free (they plug into the audio device);
    two-tone the connector black body / gold pins; render on the GPU (OptiX).
2026-07-06 Clean up schematic layout; refine connector render
    Schematic (scripts/gen_schematic.py): rework the layout for readability -
    separate J1 from the regulator (pin 3 wired straight to R9), give MICOUT and the
    capsule their own lane, space the blocks out, and offset value labels so nothing
    overlaps.
    Connector render: colour ONLY the mating pins gold (body fully black), and
    auto-butt the board into the connector body so it no longer hovers; raise the
    camera so the board reads clearly. GPU (OptiX) render.
2026-07-06 Connector render: show the true sandwich mount with modelled pins
    The board's XLR edge now sits BETWEEN three modelled gold pins on a black
    insulator insert -- pins 1 & 2 on the front (component) face, pin 3 on the back,
    board seated against the body, mating pins free. Only the pins are gold; the
    body is black; the board is tilted to read clearly.
    Pins are modelled at the board's real XLR-pad positions (netlist.py) because the
    Neutrik NC3MXX STEP is one fused solid whose pins can't be isolated. This drops
    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
2026-07-06 Convert README images from PNG to WebP (2.5 MB -> 166 KB)
    Photo-like board/connector/fit-test renders use lossy WebP (q90); the schematic
    uses lossless WebP to keep the thin lines and text crisp. Update the six README
    references and the generator scripts (render_previews.py, render_connector.py,
    gen_schematic.py) to emit WebP so regeneration stays in sync. images/schematic.svg
    is kept as the vector source.
2026-07-06 Documentation cleanup: tighten README and SPEC wording
    Smooth the prose and punctuation across both docs. Along the way,
    correct the 'How it works' intro to describe all three transistor
    stages (Q1 regulator plus the Q2/Q3 buffer pair) mapped to the three
    sections, and fill the two blank BOM function cells from the netlist
    (R1/R2/R8 and R3/R4/R6/R7/R9).
2026-07-06 Add ngspice sim harness + rev-E low-noise output-stage optimization
    sim/: headless ngspice harness generated from netlist.py (gen_deck.py,
    datasheet/vendor models, run.ps1 parse+assert with nonzero exit). Deliverable
    for git.koti issue #10.
    rev-E circuit optimization, verified by the harness (17/17 assertions):
    - Emitter-bypass output buffer: CB2/CB3 (22uF/50V) + RB2/RB3 (47R) bypass R1/R2
    so the AC output is taken at Q2/Q3's low-Z emitters. Zout 10k -> ~78R, level
    +21dB, input-referred noise -34dB, bass -26 -> -1.25dB @20Hz (git.koti #2,#11).
    - R9 100k -> 47k: zener 199 -> 408uA, off the soft knee (git.koti #3).
    - R1 10k -> 7.5k: pins balanced 351 -> 37uA (git.koti #5).
    - R8 10k -> 1k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
2026-07-06 rev-E design issues #4/#6/#8/#9 + ultrasonic frequency-response figure
    Design-phase work (no board routing; kicad_pcb regen still deferred):
    - #4: R1/R2 0603 -> 1206 for thermal margin. Measured at the OP, R1 = 67 mW
    and R2 = 50 mW continuous in the sealed shell; 1206's 250 mW leaves ~30%
    derated headroom at 80 C. Adds FP_R1206 with real KiCad pad/courtyard
    geometry; BOARD_L 34.425 -> 34.475 mm. Sim gate green (17/17).
    - #8: README solder-order / pre-tinning notes for the pin-3 back-face gap.
    - #9: record the cap-dielectric decision in netlist comments -- 50 V X7R,
    sub-50 Hz roll-off acceptable for this use case (no oversizing/polymer);
    a film/polymer A/B stays a pre-production ni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
2026-07-06 rev-E board phase: real 4-layer GND planes, Power netclass, schematic-free
    Turn the 4-layer stackup into a genuine ground shield (git.koti #1) and make the
    documented Power netclass real (#7); regenerate every artifact for rev-E.
    Board (build_pcb.py):
    - In1.Cu + In2.Cu are now solid GND planes; F.Cu/B.Cu are GND-poured after
    routing. A GND via grid stitches all four layers and a fanout via ties each
    GND pad to the planes, so the uV front end sits in an on-board Faraday cage.
    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
    [p48_fittest.scad, p48_fittest.stl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]
2026-07-06 Harden build/route/sim scripts per PR review (defensive, behavior-preserving)
    Address the Gemini Code Assist / CodeRabbit review nits on PR #1. Every change
    preserves the generated output -- board/gerbers unchanged, sim still 17/17:
    - build_pcb.py: guard fps.get(ref) / FindPadByNumber(None) in add_gnd_pad_fanout;
    use `with` + utf-8 for the two .kicad_pro patch helpers.
    - route.py: widen the stitch-via dedup tolerance to 50 um (grid-snap safe, far
    below the ~0.7 mm minimum spacing between distinct vias); `with` + utf-8 in
    confine_routing_to_outer; fail loudly if the GND net is missing before pouring.
    - sim/gen_deck.py: normalize the micro sign 'u'/'micro' so a "µF" value cannot
    sile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
